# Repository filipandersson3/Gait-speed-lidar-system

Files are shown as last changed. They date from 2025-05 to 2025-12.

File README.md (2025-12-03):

# Gait speed lidar system
Lidar system for measuring walking speed using a Garmin LIDAR-Lite v3. 

It records distance over time for a person walking in front of a lidar. This data is stored on the device until it gets extracted over USB using a python program.

This repo contains the KiCAD project, code for the microcontroller and python code for data extraction. It also contains measurement data.

This is related to my thesis project, you can find more information [here.](https://urn.kb.se/resolve?urn=urn:nbn:se:umu:diva-240602)

F. Andersson, “In-home gait speed measurement using lidar,” Dissertation, 2025.

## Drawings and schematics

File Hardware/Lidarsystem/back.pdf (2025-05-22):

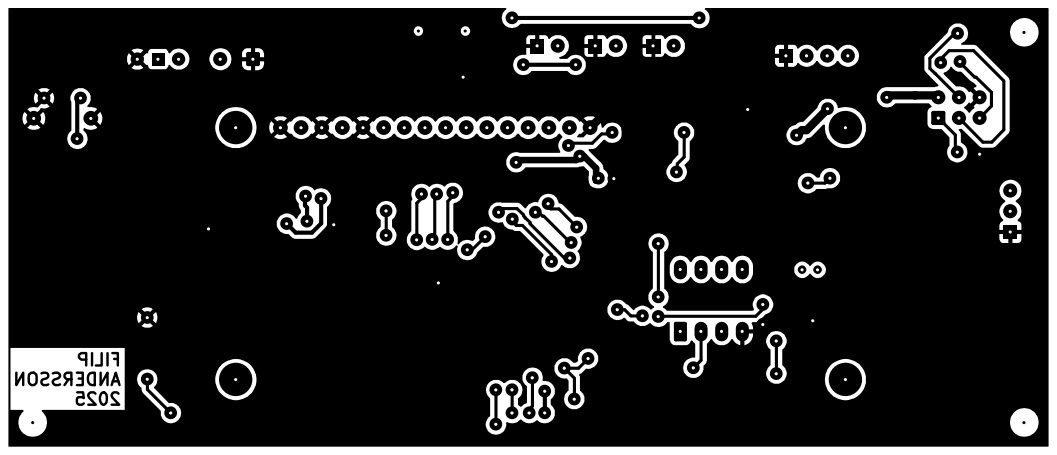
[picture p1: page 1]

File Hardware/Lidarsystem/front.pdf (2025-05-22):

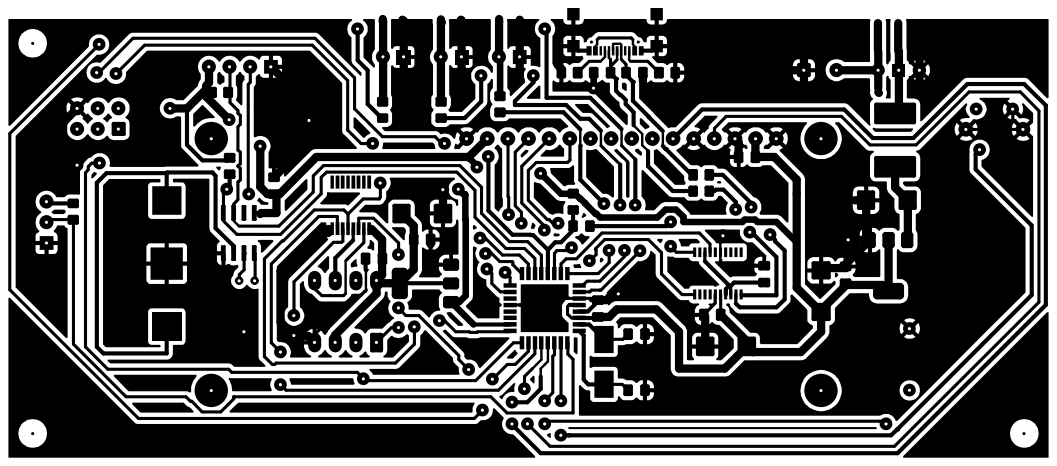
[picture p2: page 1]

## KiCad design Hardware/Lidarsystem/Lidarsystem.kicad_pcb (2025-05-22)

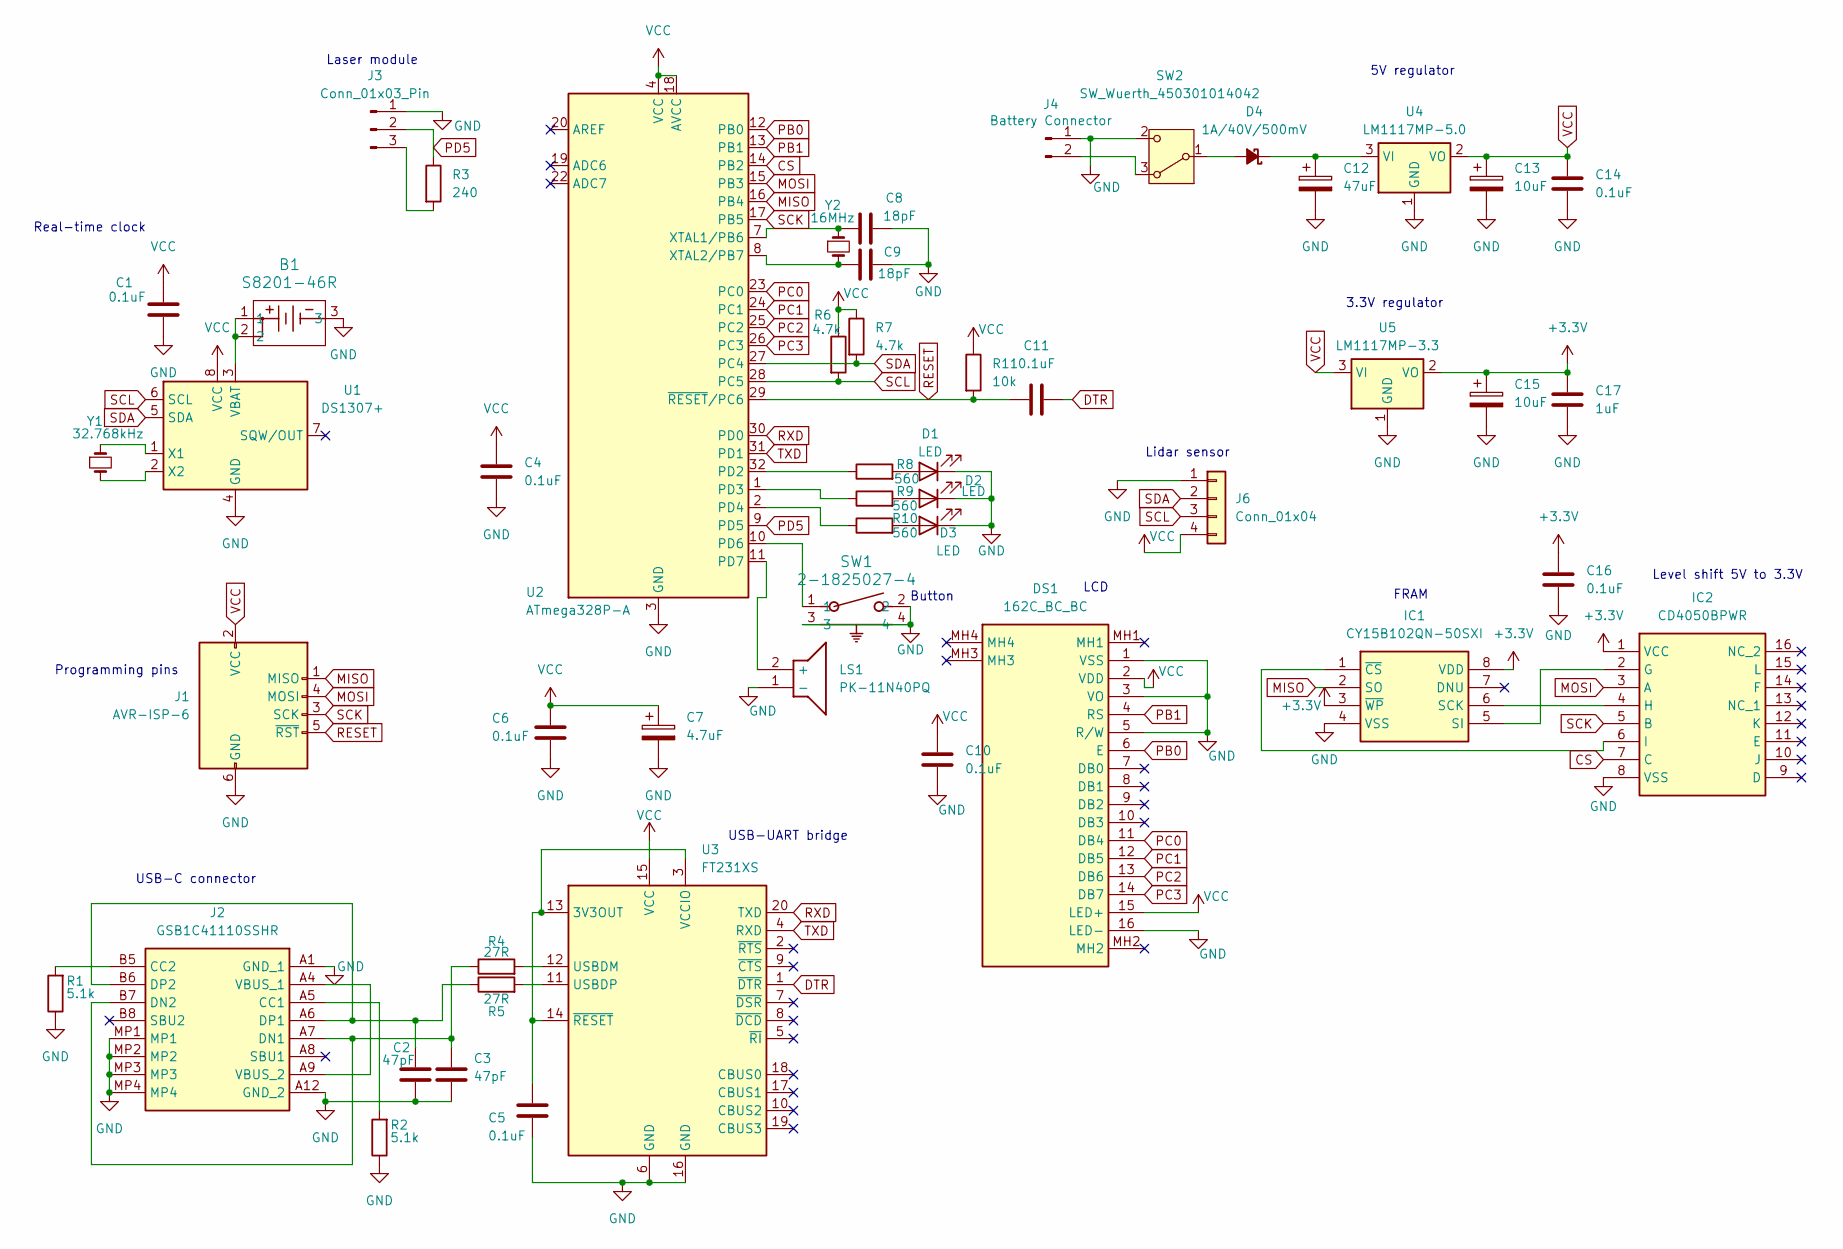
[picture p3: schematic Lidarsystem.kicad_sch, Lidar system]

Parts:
B1: S8201-46R; S8201-46R_HRW
C1, C4, C5, C6, C10, C11, C14, C16: 0.1uF; C_0805_2012Metric_Pad1.18x1.45mm_HandSolder
C2, C3: 47pF; C_0805_2012Metric_Pad1.18x1.45mm_HandSolder
C7: 4.7uF; CP_EIA-6032-15_Kemet-U_HandSolder
C8, C9: 18pF; C_0805_2012Metric_Pad1.18x1.45mm_HandSolder
C12: 47uF; CP_EIA-6032-15_Kemet-U_HandSolder
C13, C15: 10uF; CP_EIA-6032-15_Kemet-U_HandSolder
C17: 1uF; C_0805_2012Metric_Pad1.18x1.45mm_HandSolder
D1, D2, D3: LED; PinHeader_1x02_P2.54mm_Horizontal
D4: 1A/40V/500mV; D_3220_8050Metric_Pad2.65x5.15mm_HandSolder
DS1: 162C_BC_BC; 162CBCBC; Mouser Part Number 758-162CBCBC
IC1: CY15B102QN-50SXI; DIP-8_W7.62mm_Socket_LongPads; Mouser Part Number 727-CY15B102QN-50SXI
IC2: CD4050BPWR; SOP65P640X120-16N; Mouser Part Number 595-CD4050BPWR
J1: AVR-ISP-6; IDC-Header_2x03_P2.54mm_Vertical
J2: GSB1C41110SSHR; Manufacturer_Part_Number GSB1C41110SSHR
J3: Conn_01x03_Pin; PinHeader_1x03_P2.54mm_Vertical
J4: Battery Connector; SolderWire-0.15sqmm_1x02_P4mm_D0.5mm_OD1.5mm
J6: Conn_01x04; PinHeader_1x04_P2.54mm_Horizontal
LS1: PK-11N40PQ; PK11N40PQ; Mouser Part Number 539-PK-11N40PQ
R1, R2: 5.1k; R_0805_2012Metric_Pad1.20x1.40mm_HandSolder
R3: 240; R_0805_2012Metric_Pad1.20x1.40mm_HandSolder
R4, R5: 27R; R_0805_2012Metric_Pad1.20x1.40mm_HandSolder
R6, R7: 4.7k; R_0805_2012Metric_Pad1.20x1.40mm_HandSolder
R8, R9, R10: 560; R_0805_2012Metric_Pad1.20x1.40mm_HandSolder
R11: 10k; R_0805_2012Metric_Pad1.20x1.40mm_HandSolder
SW1: 2-1825027-4; SW2_1825027-H_TEC
SW2: SW_Wuerth_450301014042; SW_Slide-03_Wuerth-WS-SLTV_10x2.5x6.4_P2.54mm
U1: DS1307+; SOIC-8_3.9x4.9mm_P1.27mm
U2: ATmega328P-A; TQFP-32_7x7mm_P0.8mm
U3: FT231XS; SSOP-20_3.9x8.7mm_P0.635mm
U4: LM1117MP-5.0; SOT-223-3_TabPin2
U5: LM1117MP-3.3; SOT-223-3_TabPin2
Y1: 32.768kHz; Crystal_Round_D3.0mm_Vertical
Y2: 16MHz; Crystal_SMD_Abracon_ABM3-2Pin_5.0x3.2mm_HandSoldering

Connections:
+3.3V: C15.1, C16.1, C17.1, IC1.3 (~WP), IC1.8 (VDD), IC2.1 (VCC), U5.2 (VO)
CS: IC2.7 (C), U2.14 (PB2)
DTR: C11.1, U3.1 (~DTR)
GND: B1.3, C1.2, C2.2, C3.2, C4.2, C5.2, C6.2, C7.2, C8.1, C9.1, C10.2, C12.2, C13.2, C14.2, C15.2, C16.2, C17.2, D1.1 (K), D2.1 (K), D3.1 (K), DS1.1 (VSS), DS1.3 (VO), DS1.5 (R/W), DS1.16 (LED-), IC1.4 (VSS), IC2.8 (VSS), J1.6 (GND), J2.A1 (GND_1), J2.A12 (GND_2), J2.MP1, J2.MP2, J2.MP3, J2.MP4, J3.1, J4.1, J6.1, LS1.1 (-), R1.1, R2.1, SW1.2, SW1.3, SW1.4, SW2.2 (C), U1.4 (GND), U2.3 (GND), U2.5 (GND), U2.21 (GND), U3.6 (GND), U3.16 (GND), U4.1 (GND), U5.1 (GND)
MISO: IC1.2 (SO), J1.1 (MISO), U2.16 (PB4)
MOSI: IC2.3 (A), J1.4 (MOSI), U2.15 (PB3)
unnamed: D1.2 (A), R8.2
unnamed: D2.2 (A), R9.2
unnamed: D3.2 (A), R10.2
unnamed: D4.2 (A), SW2.1 (B)
unnamed: C12.1, D4.1 (K), U4.3 (VI)
unnamed: IC1.6 (SCK), IC2.4 (H)
unnamed: IC1.5 (SI), IC2.2 (G)
unnamed: IC1.1 (~CS), IC2.6 (I)
unnamed: J2.A5 (CC1), R2.2
unnamed: J2.B5 (CC2), R1.2
unnamed: C3.1, J2.A7 (DN1), J2.B7 (DN2), R4.1
unnamed: C2.1, J2.A6 (DP1), J2.B6 (DP2), R5.1
unnamed: J2.A4 (VBUS_1), J2.A9 (VBUS_2)
unnamed: J3.3, R3.2
unnamed: J4.2, SW2.3 (A)
unnamed: LS1.2 (+), U2.11 (PD7)
unnamed: B1.1, B1.2, U1.3 (VBAT)
unnamed: U1.1 (X1), Y1.1
unnamed: U1.2 (X2), Y1.2
unnamed: R8.1, U2.32 (PD2)
unnamed: R9.1, U2.1 (PD3)
unnamed: R10.1, U2.2 (PD4)
unnamed: SW1.1, U2.10 (PD6)
unnamed: C8.2, U2.7 (XTAL1/PB6), Y2.1
unnamed: C9.2, U2.8 (XTAL2/PB7), Y2.2
unnamed: C5.1, U3.3 (VCCIO), U3.13 (3V3OUT), U3.14 (~RESET)
unnamed: R4.2, U3.12 (USBDM)
unnamed: R5.2, U3.11 (USBDP)
PB0: DS1.6 (E), U2.12 (PB0)
PB1: DS1.4 (RS), U2.13 (PB1)
PC0: DS1.11 (DB4), U2.23 (PC0)
PC1: DS1.12 (DB5), U2.24 (PC1)
PC2: DS1.13 (DB6), U2.25 (PC2)
PC3: DS1.14 (DB7), U2.26 (PC3)
PD5: J3.2, R3.1, U2.9 (PD5)
RESET: C11.2, J1.5 (~RST), R11.2, U2.29 (~RESET/PC6)
RXD: U2.30 (PD0), U3.20 (TXD)
SCK: IC2.5 (B), J1.3 (SCK), U2.17 (PB5)
SCL: J6.3, R6.2, U1.6 (SCL), U2.28 (PC5)
SDA: J6.2, R7.2, U1.5 (SDA), U2.27 (PC4)
TXD: U2.31 (PD1), U3.4 (RXD)
VCC: C1.1, C4.1, C6.1, C7.1, C10.1, C13.1, C14.1, DS1.2 (VDD), DS1.15 (LED+), J1.2 (VCC), J6.4, R6.1, R7.1, R11.1, U1.8 (VCC), U2.4 (VCC), U2.6 (VCC), U2.18 (AVCC), U3.15 (VCC), U4.2 (VO), U5.3 (VI)

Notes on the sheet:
Real-time clock
5V regulator
FRAM
Level shift 5V to 3.3V
USB-UART bridge
Programming pins
Lidar sensor
USB-C connector
LCD
3.3V regulator
Laser module
Button

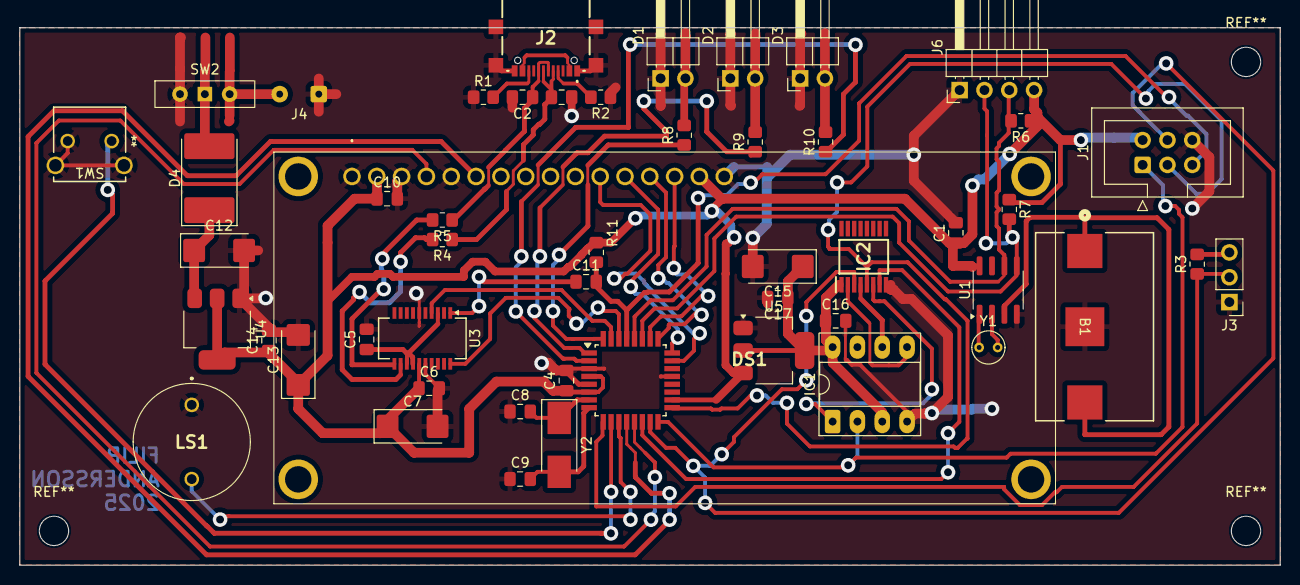
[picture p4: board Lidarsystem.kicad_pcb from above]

Board: 2 copper layers, 129.0 x 55.0 mm, 51 parts (0 on the bottom side), 48 nets.

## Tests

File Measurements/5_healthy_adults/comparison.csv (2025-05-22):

Instructed speed | Subject | Velocity (GaitRITE) | Velocity (GoHome) | Velocity (Lidar) | Notes
Normal | 1 | 0.983 | 1.07 | 0.981
Normal | 1 | 1.238 | 1.4 | 1.24
Normal | 1 | 1.193 | 1.32 | 1.202
Normal | 1 | 1.202 | 1.31 | 1.206
Normal | 1 | 1.181 | 1.32 | 1.203
Fast | 1 | 1.747 | 1.99 | 1.762
Fast | 1 | 1.776 | 2.02 | 1.804
Fast | 1 | 1.75 | 1.98 | 1.759
Fast | 1 | 1.846 | 2.07 | 1.852
Fast | 1 | 1.858 | 2.1 | 1.883
Slow | 1 | 0.37 | 0.4 | 0.37
Slow | 1 | 0.492 | 0.55 | 0.506
Slow | 1 | 0.519 | 0.58 | 0.528
Slow | 1 | 0.456 | 0.5 | 0.468
Slow | 1 | 0.533 | 0.59 | 0.543
Normal | 2 | 0.849 | 0.96 | 0.864
Normal | 2 | 0.914 | 1.04 | 0.924
Normal | 2 | 0.971 | 1.09 | 0.969
Normal | 2 | 1.016 | 1.13 | 1.021
Normal | 2 | 0.978 | 1.11 | 0.996
Fast | 2 | 1.478 | 1.69 | 1.492
Fast | 2 | 1.511 | 1.73 | 1.53
Fast | 2 | 1.514 | 1.7 | 1.528
Fast | 2 | 1.492 | 1.71 | 1.506
Fast | 2 | 1.472 | 1.67 | 1.485
Slow | 2 | 0.787 | 0.86 | 0.783
Slow | 2 | 0.779 | 0.86 | 0.78
Slow | 2 | 0.743 | 0.83 | 0.747
Slow | 2 | 0.823 | 0.91 | 0.826
Slow | 2 | 0.817 | 0.94 | 0.844
Normal | 3 | 1.209 | 1.34 | 1.223
Normal | 3 | 1.177 | 1.29 | 1.187
Normal | 3 | 1.307 | 1.44 | 1.327
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

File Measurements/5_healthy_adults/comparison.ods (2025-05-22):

Instructed speed | Subject | Velocity (GaitRITE) | Velocity (GoHome) | Velocity (Lidar) | Notes
Normal | 1 | 0.983 | 1.07 | 0.981
Normal | 1 | 1.238 | 1.4 | 1.24
Normal | 1 | 1.193 | 1.32 | 1.202
Normal | 1 | 1.202 | 1.31 | 1.206
Normal | 1 | 1.181 | 1.32 | 1.203
Fast | 1 | 1.747 | 1.99 | 1.762
Fast | 1 | 1.776 | 2.02 | 1.804
Fast | 1 | 1.75 | 1.98 | 1.759
Fast | 1 | 1.846 | 2.07 | 1.852
Fast | 1 | 1.858 | 2.1 | 1.883
Slow | 1 | 0.37 | 0.4 | 0.37
Slow | 1 | 0.492 | 0.55 | 0.506
Slow | 1 | 0.519 | 0.58 | 0.528
Slow | 1 | 0.456 | 0.5 | 0.468
Slow | 1 | 0.533 | 0.59 | 0.543
Normal | 2 | 0.849 | 0.96 | 0.864
Normal | 2 | 0.914 | 1.04 | 0.924
Normal | 2 | 0.971 | 1.09 | 0.969
Normal | 2 | 1.016 | 1.13 | 1.021
Normal | 2 | 0.978 | 1.11 | 0.996
Fast | 2 | 1.478 | 1.69 | 1.492
Fast | 2 | 1.511 | 1.73 | 1.53
Fast | 2 | 1.514 | 1.7 | 1.528
Fast | 2 | 1.492 | 1.71 | 1.506
Fast | 2 | 1.472 | 1.67 | 1.485
Slow | 2 | 0.787 | 0.86 | 0.783
Slow | 2 | 0.779 | 0.86 | 0.78
Slow | 2 | 0.743 | 0.83 | 0.747
Slow | 2 | 0.823 | 0.91 | 0.826
Slow | 2 | 0.817 | 0.94 | 0.844
Normal | 3 | 1.209 | 1.34 | 1.223
Normal | 3 | 1.177 | 1.29 | 1.187
Normal | 3 | 1.307 | 1.44 | 1.327
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

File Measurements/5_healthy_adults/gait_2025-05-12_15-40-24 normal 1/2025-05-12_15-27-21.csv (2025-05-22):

Time (s) | Distance (m)
0.02 | 1.04
0.04 | 1.06
0.06 | 1.07
0.08 | 1.08
0.1 | 1.09
0.12 | 1.11
0.14 | 1.11
0.16 | 1.14
0.18 | 1.14
0.2 | 1.16
0.22 | 1.18
0.24 | 1.21
0.26 | 1.24
0.28 | 1.25
0.3 | 1.28
0.32 | 1.31
0.34 | 1.34
0.36 | 1.37
0.38 | 1.38
0.4 | 1.4
0.42 | 1.42
0.44 | 1.44
0.46 | 1.48
0.48 | 1.49
0.5 | 1.5
0.52 | 1.53
0.54 | 1.56
0.56 | 1.58
0.58 | 1.6
0.6 | 1.62
0.62 | 1.63
0.64 | 1.64
0.66 | 1.66
0.68 | 1.69
0.7 | 1.7
0.72 | 1.72
0.74 | 1.73
0.76 | 1.76
0.78 | 1.78
0.8 | 1.82
0.82 | 1.83
0.84 | 1.84
0.86 | 1.86
0.88 | 1.88
0.9 | 1.9
0.92 | 1.92
0.94 | 1.94
0.96 | 1.97
0.98 | 1.99
1.0 | 2.02
1.02 | 2.06
1.04 | 2.09
1.06 | 2.11
1.08 | 2.12
1.1 | 2.15
1.12 | 2.18
1.14 | 2.19
1.16 | 2.2
1.18 | 2.21
1.2 | 2.23
1.22 | 2.27
1.24 | 2.28
1.26 | 2.3
1.28 | 2.32
1.3 | 2.34
1.32 | 2.37
1.34 | 2.4
1.36 | 2.4
1.38 | 2.44
1.4 | 2.46
1.42 | 2.47
1.44 | 2.49
1.46 | 2.51
1.48 | 2.52
1.5 | 2.53
1.52 | 2.55
1.54 | 2.58
1.56 | 2.59
1.58 | 2.62
1.6 | 2.63
1.62 | 2.65
1.64 | 2.68
1.66 | 2.7
1.68 | 2.73
1.7 | 2.75
1.72 | 2.76
1.74 | 2.79
1.76 | 2.82
1.78 | 2.83
1.8 | 2.85
1.82 | 2.88
1.84 | 2.89
1.86 | 2.93
1.88 | 2.94
1.9 | 2.95
1.92 | 2.98
1.94 | 3.01
1.96 | 3.04
1.98 | 3.04
2.0 | 3.05
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

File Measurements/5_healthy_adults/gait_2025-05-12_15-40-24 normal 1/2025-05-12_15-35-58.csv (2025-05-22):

Time (s) | Distance (m)
0.02 | 1.04
0.04 | 1.06
0.06 | 1.07
0.08 | 1.1
0.1 | 1.11
0.12 | 1.13
0.14 | 1.15
0.16 | 1.18
0.19 | 1.2
0.2 | 1.21
0.22 | 1.23
0.24 | 1.25
0.26 | 1.27
0.28 | 1.31
0.3 | 1.34
0.32 | 1.36
0.34 | 1.38
0.36 | 1.4
0.38 | 1.43
0.4 | 1.45
0.42 | 1.48
0.44 | 1.49
0.46 | 1.52
0.48 | 1.55
0.5 | 1.57
0.52 | 1.6
0.54 | 1.62
0.56 | 1.64
0.58 | 1.66
0.6 | 1.7
0.62 | 1.72
0.64 | 1.76
0.66 | 1.8
0.68 | 1.83
0.7 | 1.85
0.72 | 1.88
0.74 | 1.92
0.76 | 1.94
0.78 | 1.96
0.8 | 1.98
0.82 | 2.01
0.84 | 2.04
0.86 | 2.06
0.88 | 2.09
0.9 | 2.12
0.92 | 2.14
0.94 | 2.16
0.96 | 2.19
0.98 | 2.23
1.0 | 2.22
1.02 | 2.25
1.04 | 2.27
1.06 | 2.29
1.08 | 2.31
1.1 | 2.35
1.12 | 2.38
1.14 | 2.4
1.16 | 2.43
1.18 | 2.45
1.2 | 2.48
1.22 | 2.5
1.24 | 2.52
1.26 | 2.54
1.28 | 2.55
1.3 | 2.57
1.32 | 2.6
1.34 | 2.62
1.36 | 2.64
1.38 | 2.67
1.4 | 2.7
1.42 | 2.72
1.44 | 2.74
1.46 | 2.77
1.48 | 2.8
1.5 | 2.82
1.52 | 2.85
1.54 | 2.87
1.56 | 2.89
1.58 | 2.92
1.6 | 2.94
1.62 | 2.98
1.64 | 2.98
1.66 | 3.03
1.68 | 3.04
1.7 | 3.07
1.72 | 3.1
1.74 | 3.11
1.76 | 3.14
1.78 | 3.18
1.8 | 3.22
1.82 | 3.25
1.84 | 3.28
1.87 | 3.32
1.88 | 3.33
1.9 | 3.37
1.92 | 3.38
1.94 | 3.4
1.96 | 3.44
1.98 | 3.46
2.0 | 3.48
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

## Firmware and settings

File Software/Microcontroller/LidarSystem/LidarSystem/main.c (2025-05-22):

/*
* LidarSystem.c
*
* Created: 2025-04-02 11:13:17
* Author : Filip Andersson
*/
#include "main.h"

volatile uint16_t lcd_counter = 0;
FILE lcdstream = FDEV_SETUP_STREAM(LCD_send_char, NULL, _FDEV_SETUP_WRITE);
char strbuf[33];
uint16_t distance;
uint32_t counter;
volatile uint16_t time_since_start;
uint8_t strupdated;
volatile uint8_t lcdcooldown;
uint16_t meas_time;
uint16_t meas_cplt;
uint8_t timeseries_start;
uint16_t timebuf[21];
uint16_t distbuf[21];
uint16_t meas_index;
uint8_t do_measurement;
uint8_t meas_ongoing;
uint16_t saved_distance;
uint32_t curr_addr;
uint32_t curr_startbyte_addr;
uint8_t startbyte_stored = 0;
uint8_t endbyte_stored = 1;
volatile uint16_t lasercounter;
uint32_t buzzer_beep_counter;
volatile uint16_t buzzer_beep_length;
volatile uint8_t buzzer_beep_start;
uint16_t counter2;
uint8_t counterremainder;
#define RECEIVEBUF_SIZE  60
char receivebuf[RECEIVEBUF_SIZE];
uint8_t menu_state = 0;
volatile uint32_t millis;

#define LIDAR_ADDR  0xC4      // I2C device address of lidar, see datasheet

#define MIN_DISTANCE	100
#define MAX_DISTANCE	350

#define BUZZER_PORT     PORTD
#define BUZZER_DDR      DDRD
#define BUZZER_PIN      PIND
#define BUZZER_BIT      PORTD7

#define LASER_PORT		PORTD
#define LASER_DDR		DDRD
#define LASER_PIN		PIND
#define LASER_BIT		PORTD5

#define BTN1_PORT		PORTD
#define BTN1_DDR		DDRD
#define BTN1_PIN		PIND
#define BTN1_BIT		PORTD6

// Timer constants (in milliseconds)
#define MEASUREMENT_TIMEOUT 60000 // maximum measurement length
#define SAMPLE_PERIOD 20 // time between samples
#define BUZZER_METRONOME 500 // how long between short buzzer beeps when walking
#define BUZZER_FREQ_DEFAULT 1000 // Hz

int main(void) {
	FILE uartstream = FDEV_SETUP_STREAM(TransmitByte, NULL, _FDEV_SETUP_WRITE);
	
	DDRD = 0b10111100;
	SETBIT(PORTD,PORTD2);
	SETBIT(PORTD,PORTD3);
	SETBIT(PORTD,PORTD4);
	//PORTD = 0x04;
	SETBIT(BTN1_PORT, BTN1_BIT); //pull-up, input
	
	LASER_DDR |= (1<<LASER_BIT); // set as output
	BUZZER_DDR |= (1<<BUZZER_BIT);
	
	FRAM_SPI_Init();
	LCD_init();
	i2c_init();
	uart1_init(3); //uart init 250000 bps
	stdout = &uartstream;
	printf("UART started...\r\n");
	timer1_init();
	timer2_init();
	_delay_ms(50);
	
	fprintf(&lcdstream, "Starting...");
	
	//FRAM_Write32(0x0, 0x04);
	curr_addr = FRAM_Read32(0x0);
	curr_startbyte_addr = curr_addr;
	
	// try to read a line from serial
	DateTime calibr_time;
	int valid_msg_received = 0;
	int keep_data;
	// get datetime from computer to calibrate
	// read lines from buffer until scanf success or timeout
	int startmillis = millis;
	while(!valid_msg_received || millis-startmillis < 500) {
		if (try_read_from_pc(&calibr_time, &keep_data) > 6) { //valid message received from pc?
			valid_msg_received = 1;
			DS1307_set(calibr_time);
			transmit_stored_data();
			if (keep_data == 0) {
				// set last address, "removing" all data after the address
				FRAM_Write32(0x0, 0x04);
			}
		}
	}
	
	FRAM_Write16(255992, (uint16_t)0xDEADBEEF);
	if (FRAM_Read16(255992) != (uint16_t)0xDEADBEEF) {
		LCD_clear();
		fprintf(&lcdstream, "memory doesn't");
		LCD_cursor_pos(40);
		fprintf(&lcdstream, "work :(");
		while(FRAM_Read16(255992) != (uint16_t)0xDEADBEEF){
			printf("memory doesn't work\n");
			FRAM_Write16(255992, (uint16_t)0xDEADBEEF);
			_delay_ms(100);
		};
	}
	FRAM_Write16(255992, 0x0);
	
	DateTime testtime = DS1307_now(); //get time
	start_beep(523, 180); // play some beeps until 1 second passed
	_delay_ms(300);
	start_beep(784, 180);
	_delay_ms(300);
	_delay_ms(450);
	if (DS1307_now().year < 2025U || DS1307_now().second-testtime.second < 1) { // check clock
		LCD_clear();
		fprintf(&lcdstream, "RTC doesn't");
		LCD_cursor_pos(40);
		fprintf(&lcdstream, "work :(");
		while(1){
			printf("RTC doesn't work\n");
			_delay_ms(100);
		};
	}
	
	/* Replace with your application code */
	while (1)
	{
		int prev_dist = distance;
		if (do_measurement) {
			distance = lidar_read_dist();
			if (timeseries_start) {
				timebuf[meas_index] = time_since_start;
				distbuf[meas_index++] = distance;
			}
			do_measurement = 0;
		}
		if(meas_index >= 20) {
			store_in_mem();
		}
		if (lcdcooldown == 0) {
			if (distance != prev_dist) {
				LCD_clear();
				 if (menu_state == 0) {
					LCD_cursor_pos(0);
					fprintf(&lcdstream, "Start measuring?");
					LCD_cursor_pos(40);
					fprintf(&lcdstream, "Distance: %.2lf m", distance/100.0);
				} else if (menu_state == 1) {
					LCD_cursor_pos(0);
					fprintf(&lcdstream, "Distance: %.2lf m", distance/100.0);
					LCD_cursor_pos(40);
					fprintf(&lcdstream, "Time: %.2lf s", time_since_start/1000.0);
				} else if (menu_state == 2) {
					LCD_cursor_pos(0);
					fprintf(&lcdstream, "Data saved.");
					LCD_cursor_pos(40);
					fprintf(&lcdstream, "Speed: %.2lf m/s", ((MAX_DISTANCE-MIN_DISTANCE)*10.0)/(meas_time));
					_delay_ms(100);
				} else if (menu_state == 3) {
					LCD_cursor_pos(0);
					fprintf(&lcdstream, "Wall distance low");
					LCD_cursor_pos(40);
					fprintf(&lcdstream, "%.2lfm < %.2lfm", distance/100.0, (MAX_DISTANCE+50)/100.0);
					_delay_ms(1000);
					menu_state = 0;
				}
				
				if ((menu_state == 0 || menu_state == 2) && IS_BIT_CLEAR(BTN1_PIN,BTN1_BIT)) {
					menu_state = 1;
				}
				if (distance < MAX_DISTANCE+50 && IS_BIT_CLEAR(BTN1_PIN,BTN1_BIT)) {
					menu_state = 3;
				}
				
				
				lcdcooldown = 1;
			}
		}
		// in measuring mode
		if (menu_state == 1) {
			if (distance < MIN_DISTANCE+3 && distance > MIN_DISTANCE) {
				start_beep(BUZZER_FREQ_DEFAULT, 100);
				SETBIT(PORTD,PORTD2);
				time_since_start = 0;
				timeseries_start = 1;
				} else {
				CLEARBIT(PORTD,PORTD2);
			}
			if (distance < MAX_DISTANCE+20 && distance > MIN_DISTANCE-20) {
				SETBIT(PORTD,PORTD3);
				} else {
				if (timeseries_start) {
					cancel_measurement();
				}
				CLEARBIT(PORTD,PORTD3);
			}
			if (distance < MAX_DISTANCE+5 && distance > MAX_DISTANCE) {
				CLEARBIT(PORTD,PORTD3);
				SETBIT(PORTD,PORTD4);
				if (timeseries_start) {
					meas_time = time_since_start;
					endbyte_stored = 0;
					store_in_mem();
					curr_startbyte_addr = curr_addr;
					startbyte_stored = 0;
					time_since_start = 0;
					timeseries_start = 0;
					menu_state = 2;
					start_beep(523, 150);
					_delay_ms(150);
					start_beep(784, 150);
					_delay_ms(150);
					start_beep(1046, 150);
					_delay_ms(150);
				}
				} else {
				CLEARBIT(PORTD,PORTD4);
			}
		}
	}
}

uint8_t try_read_from_pc(DateTime *calibr_time, int *keep_data) {
	uint8_t receive_count = 0;
	while (DataInReceiveBuffer() && receive_count < RECEIVEBUF_SIZE-1) {
		receivebuf[receive_count] = ReceiveByte();
		receivebuf[receive_count+1] = 0;
		if (receivebuf[receive_count] == '\n') {
			receivebuf[receive_count] = 0;
			break;
		}
		receive_count++;
	}
	
	int res = sscanf(receivebuf,
	"%4d-%d-%d_%d-%d-%d %d",
	&calibr_time->year,
	&calibr_time->month,
	&calibr_time->day,
	&calibr_time->hour,
	&calibr_time->minute,
	&calibr_time->second,
	keep_data);
	return res;
}

void transmit_stored_data(void) {
	printf("CONTACT\n");
	uint8_t found_startbyte = 0;
	for (int i = 4; i < curr_addr; i+=2) {
		uint16_t value = FRAM_Read16(i);
		if (value == 0xFFFF) {
			printf("END\n");
			found_startbyte = 0;
		}
		if (found_startbyte != 0) {
			if ((i-found_startbyte)%4 == 0) {
				printf("%.2lf\n", value/1000.0);
				} else {
				printf("%.2lf, ", value/100.0);
			}
		}
		if (value == 0xFFFE) {
			found_startbyte = i;
			DateTime timestamp;
			timestamp.year = FRAM_Read16(i+2);
			timestamp.month = FRAM_Read16(i+4);
			timestamp.day = FRAM_Read16(i+6);
			timestamp.hour = FRAM_Read16(i+8);
			timestamp.minute = FRAM_Read16(i+10);
			timestamp.second = FRAM_Read16(i+12);
			i += 12;
			printf("START %d-%d-%d_%d-%d-%d\n", timestamp.year,
			timestamp.month,
			timestamp.day,
			timestamp.hour,
			timestamp.minute,
			timestamp.second);
		}
	}
	printf("TRANSFER COMPLETE\n");
}

uint16_t lidar_read_dist(void) {
	uint8_t ret = 1;
	i2c_start_wait(LIDAR_ADDR+I2C_WRITE);     // set device address and write mode
	i2c_write(0x00);                        // write address
	i2c_write(0x04);                        // write value
	i2c_stop();
	
	while (IS_BIT_SET(ret,0)) {
		i2c_start_wait(LIDAR_ADDR+I2C_WRITE);     // set device address and write mode
		i2c_write(0x01);                        // write address
		i2c_rep_start(LIDAR_ADDR+I2C_READ);       // read mode
		ret = i2c_readNak();                    // read one byte
		i2c_stop();
	}
	
	i2c_start_wait(LIDAR_ADDR+I2C_WRITE);     // set device address and write mode
	i2c_write(0x8f);                        // write address
	i2c_rep_start(LIDAR_ADDR+I2C_READ);       // read mode
	uint8_t highByte = i2c_readNak();         // read one byte
	i2c_stop();
	
	i2c_start_wait(LIDAR_ADDR+I2C_WRITE);     // set device address and write mode
	i2c_write(0x90);                        // write address
	i2c_rep_start(LIDAR_ADDR+I2C_READ);       // read mode
	uint8_t lowByte = i2c_readNak();         // read one byte
	i2c_stop();
	
	return ((highByte << 8) | lowByte);
}

void print_values(void) {
	for (int i = 0; i < meas_index; i++) {
		printf("%.2lf, ", distbuf[i]/100.0);
		printf("%.2lf\n", timebuf[i]/1000.0);
	}
	meas_index = 0;
}

void store_in_mem(void) {
	if (!startbyte_stored) {
		curr_startbyte_addr = curr_addr;
		curr_addr += 14;
		startbyte_stored = 1;
	}
	for (int i = 0; i < meas_index; i++) {
		if (curr_addr > 255990) {
			cancel_measurement();
			LCD_clear();
			LCD_cursor_pos(0);
			fprintf(&lcdstream, "Memory full.");
			while (1);
		}
		FRAM_Write16(curr_addr,distbuf[i]);
		curr_addr += 2;
		FRAM_Write16(curr_addr,timebuf[i]);
		curr_addr += 2;
	}
	if (!endbyte_stored) {
		DateTime dt = DS1307_now();
		FRAM_Write16(curr_startbyte_addr,0xFFFE);
		FRAM_Write16(curr_startbyte_addr+2,dt.year);
		FRAM_Write16(curr_startbyte_addr+4,dt.month);
		FRAM_Write16(curr_startbyte_addr+6,dt.day);
		FRAM_Write16(curr_startbyte_addr+8,dt.hour);
		FRAM_Write16(curr_startbyte_addr+10,dt.minute);
		FRAM_Write16(curr_startbyte_addr+12,dt.second);
		FRAM_Write16(curr_addr,0xFFFF);
		curr_addr += 2;
		FRAM_Write32(0x0,curr_addr);
		endbyte_stored = 1;
	}
	meas_index = 0;
}

void cancel_measurement(void) {
	FRAM_Write32(0x0,curr_startbyte_addr); //"erase" data from last startbyte
	curr_addr = curr_startbyte_addr;
	startbyte_stored = 0;
	time_since_start = 0;
	timeseries_start = 0;
	meas_index = 0;
}

void start_beep(uint16_t frequency, uint16_t length) {
	uint8_t ocr = (uint8_t)((F_CPU / (8UL * 64UL * frequency)) - 1);
	if (ocr > 255) ocr = 255;
	OCR2A = ocr; // change timer compare register for frequency
	buzzer_beep_start = 1;
	buzzer_beep_length = length;
	TIMSK2 |= (1 << OCIE2A); // start timer interrupts
}

void timer1_init() {
	// set timer1 to CTC mode with OCR1A as the compare value
	TCCR1A = 0; // normal operation
	TCCR1B = (1 << WGM12) | (1 << CS11) | (1 << CS10); // CTC mode, prescaler 64
	OCR1A = 249; // for 1ms interrupt
	TIMSK1 = (1 << OCIE1A); // timer1 compare A interrupt
	sei(); // enable interrupts
}

void timer2_init() {
	// CTC Mode
	TCCR2A = (1 << WGM21);

	// Prescaler = 64
	TCCR2B = (1 << CS22) | (1 << CS21);

	// Output Compare Match A Interrupt
	TIMSK2 = (1 << OCIE2A);

	TCNT2 = 0;
}


ISR(USART_RX_vect) {
	UART_RX_interrupt();
}

ISR(USART_UDRE_vect) {
	UART_TX_interrupt();
}

ISR(TIMER1_COMPA_vect) { //triggered every millisecond
	millis++;
	if (millis%SAMPLE_PERIOD == 0) {
		do_measurement = 1;
	}
	if (timeseries_start) {
		time_since_start++;
		if (time_since_start == MEASUREMENT_TIMEOUT) {
			//cancel_measurement();
			time_since_start = 0;
		}
		if ((time_since_start%BUZZER_METRONOME==0) && distance < MAX_DISTANCE+3 && distance > MIN_DISTANCE) {
			start_beep(1000, 60);
		}
	}
	
	////////////// LASER //////////////
	lasercounter++;
	if (lasercounter == 200) {
		CLEARBIT(PORTD, PORTD5);
	}
	if (lasercounter == 1000) {
		// if button pressed, activate
		if (IS_BIT_CLEAR(BTN1_PIN,BTN1_BIT)) {
			SETBIT(PORTD, PORTD5);
		}
		lasercounter = 0;
	}
	
	////////////// BUZZER ///////////
	if (buzzer_beep_start == 1) {
		buzzer_beep_length--;
		if (buzzer_beep_length <= 0) {
			buzzer_beep_length = 0;
			buzzer_beep_start = 0;
			TIMSK2 &= ~(1 << OCIE2A); // stop timer interrupts
		}
	}
	
	////////////// LCD //////////////
	// lcd refresh (lcd clear takes 2ms)
	lcd_counter++;
	if (lcd_counter == 3) {
		lcdcooldown = 0;
	}
	if (lcd_counter == 40) {
		lcd_counter = 0;
	}
}

ISR(TIMER2_COMPA_vect) {
	////////////// BUZZER //////////////
	if (buzzer_beep_start == 1) {
		FLIPBIT(BUZZER_PORT,BUZZER_BIT);
	}
}

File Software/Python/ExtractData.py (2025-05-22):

import sys
import time
import serial
import serial.tools.list_ports
import csv
import os
from datetime import datetime
import matplotlib.pyplot as plt
import numpy as np
from pick import pick
import pandas as pd

def read_series_to_csv(port, keep_device_data):
    #open serial port with error handling
    try:
        ser = serial.Serial(port, 250000, timeout=1)
    except serial.SerialException as e:
        sys.exit(f"Can't open {port}: {e}")
    if not ser.is_open:
        sys.exit(f"Can't open {port}")
    
    # keep sending until device replies
    while ser.readline().decode(errors='ignore').strip() != "CONTACT":
        data = bytearray(datetime.now().strftime("%Y-%m-%d_%H-%M-%S").encode("ascii","strict"))
        if keep_device_data:
            data.extend(b' 1 \n')
        else:
            data.extend(b' 0 \n')
        ser.write(data) # write if device memory should be cleared and current datetime to synchronize device RTC
        ser.flush()
    output_folder = None
    started = False
    times = []
    distances = []

    while True:
        line = ser.readline().decode(errors='ignore').strip()
        if line == "": 
            continue # keep reading until you get a non-empty line
        if line == "TRANSFER COMPLETE":
            break
        if line.startswith("START"):
            # convert the string to datetime
            timestamp = datetime.strptime(line, "START %Y-%m-%d_%H-%M-%S")
            started = True
            times = []
            distances = []

            # create the output folder once on the first START
            if output_folder is None:
                output_folder = mydir = os.path.join(
                    os.getcwd(), 
                    datetime.now().strftime('gait_%Y-%m-%d_%H-%M-%S'))
                try:
                    os.makedirs(mydir)
                except OSError as e:
                    sys.exit(f"Couldn't create output folder: {e}")
            continue

        if line == "END":
            # save as .csv
            timestamp_string = timestamp.strftime("%Y-%m-%d_%H-%M-%S")
            filename = os.path.join(output_folder, f"{timestamp_string}.csv")
            df = pd.DataFrame({"Time (s)" : times, "Distance (m)" : distances})
            df.to_csv(filename, index=False)
            started = False
            continue
        if started:
            try:
                print(line)
                # read the comma-separated values
                values = [float(x.strip()) for x in line.split(",")]
                distances.append(values[0])
                times.append(values[1])
            except ValueError:
                print("Skip invalid data line")
    
    return output_folder            

def plot_series_from_csv(folder_path, selected_list):
    for filename in selected_list:
        file_path = os.path.join(folder_path, filename)
        times = []
        distances = []

        with open(file_path, 'r') as file:
            reader = csv.reader(file)
            for row in reader:
                try:
                    distance, time = float(row[1]), float(row[0])
                    distances.append(distance)
                    times.append(time)
                except ValueError:
                    continue

        times_np = np.array(times)
        distances_np = np.array(distances)

        # linear regression
        slope, intercept = np.polyfit(times_np, distances_np, 1)
        regression_line = slope * times_np + intercept

        plt.figure()
        plt.plot(times_np, distances_np, 'o', color='blue', markersize=4, label='Data')
        plt.plot(times_np, regression_line, '--', color='red', linewidth=1.8, label='Linear Fit')

        equation = f"y = {slope:.4f}x + {intercept:.4f}"
        plt.annotate(equation, xy=(0.05, 0.95), xycoords='axes fraction',
                        fontsize=10, color='red', ha='left', va='top',
                        bbox=dict(boxstyle='round,pad=0.3', edgecolor='red', facecolor='white', alpha=0.8))

        plt.xlabel('Time (s)')
        plt.ylabel('Distance (m)')
        plt.title(f'Distance vs Time: {filename}')
        plt.legend()
        plt.grid(True)
        plt.tight_layout()

        # save svg
        svg_path = os.path.join(folder_path, f"{filename}.svg")
        plt.savefig(svg_path, format='svg')
        print(f"Saved vector plot: {svg_path}")

    plt.show()


def main():
    ports = list(serial.tools.list_ports.comports())
    if not ports:
        print("No COM ports found. Make sure the device is plugged in via USB and try again.")
        return
    # list COM ports and let user choose one
    title = 'Available COM ports: '
    options = ports
    option, index = pick(options, title)
    selected_port = ports[index].device

    title = 'Do you want to copy or move the data to this PC? '
    options = ("Copy","Move (erases data from lidar device after transfer)")
    option, index = pick(options, title)
    if index == 0:
        keep_device_data = True
    else:
        keep_device_data = False

    # read data from COM port and output to .csv file
    output_folder = read_series_to_csv(selected_port, keep_device_data)

    if output_folder and os.path.exists(output_folder):
        folder_list = []
        folder_list.append("All")
        folder_list.append("None")
        for filename in sorted(os.listdir(output_folder)):
            if filename.endswith('.csv'):
                folder_list.append(filename)
        title = 'Visualize data series with linear regression and save figures? (press SPACE to mark, ENTER to continue)'
        options = folder_list
        selected = pick(options, title, multiselect=True, min_selection_count=1)
        selected_list = [item[0] for item in selected]
        if ("All" in selected_list):
            folder_list.remove("All")
            folder_list.remove("None")
            plot_series_from_csv(output_folder, folder_list)
        elif not "None" in selected_list:
            plot_series_from_csv(output_folder, selected_list)
    else:
        print("No data was found on the device.")

if __name__ == "__main__":
    main()
